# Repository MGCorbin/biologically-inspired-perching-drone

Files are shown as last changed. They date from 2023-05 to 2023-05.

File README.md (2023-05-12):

# Biologically Inspired Perching Drone
This project is inspired by the claws of birds of prey and their unique biological ratcheting mechanism that allows them to tightly and securely grip with their talons without relying entirely on muscular strength.

The files within the project contain both the hardware and software required to build a claw attachment for a drone.

## Directory Structure
* [claw_control/](./biologically-inspired-perching-drone/claw_control)  - folder containing firmware
  * [include/](./biologically-inspired-perching-drone/claw_control/include)
  * [lib/](./biologically-inspired-perching-drone/claw_control/lib)
  * [src/](./biologically-inspired-perching-drone/claw_control/src)
  * [test/](./biologically-inspired-perching-drone/claw_control/test)
  * [platformio.ini](./biologically-inspired-perching-drone/claw_control/platformio.ini)
* [hardware/](./biologically-inspired-perching-drone/hardware)          - folder containing hardware (both electronics & CAD)
* [README.md](./biologically-inspired-perching-drone/README.md)

## Hardware
In this folder you can find STL files that can be downloaded for 3D printing and the original parameterised SolidWorks CAD files and assemblies that can be modified to customise/remix the design to suit different drone and hardware configurations. 
* [Bivalve_7_talon/](./biologically-inspired-perching-drone/hardware/Bivalve_7_talon) - folder containing the Solidworks part files and STL files for a version of the bivalve claw mechanism with additional claws (3-4 config).
* [Bivalve_Claw_Mechanism/](./biologically-inspired-perching-drone/hardware/Bivalve_Claw_Mechanism) - folder containing the SolidWorks part files, STL files, and assembly for the bivalve claw mechanism design.
* [Tendon_Arm/](./biologically-inspired-perching-drone/hardware/Tendon_Arm) - folder contianing the STL files used during the testing and development of the tendon claw design.

## Drone Image
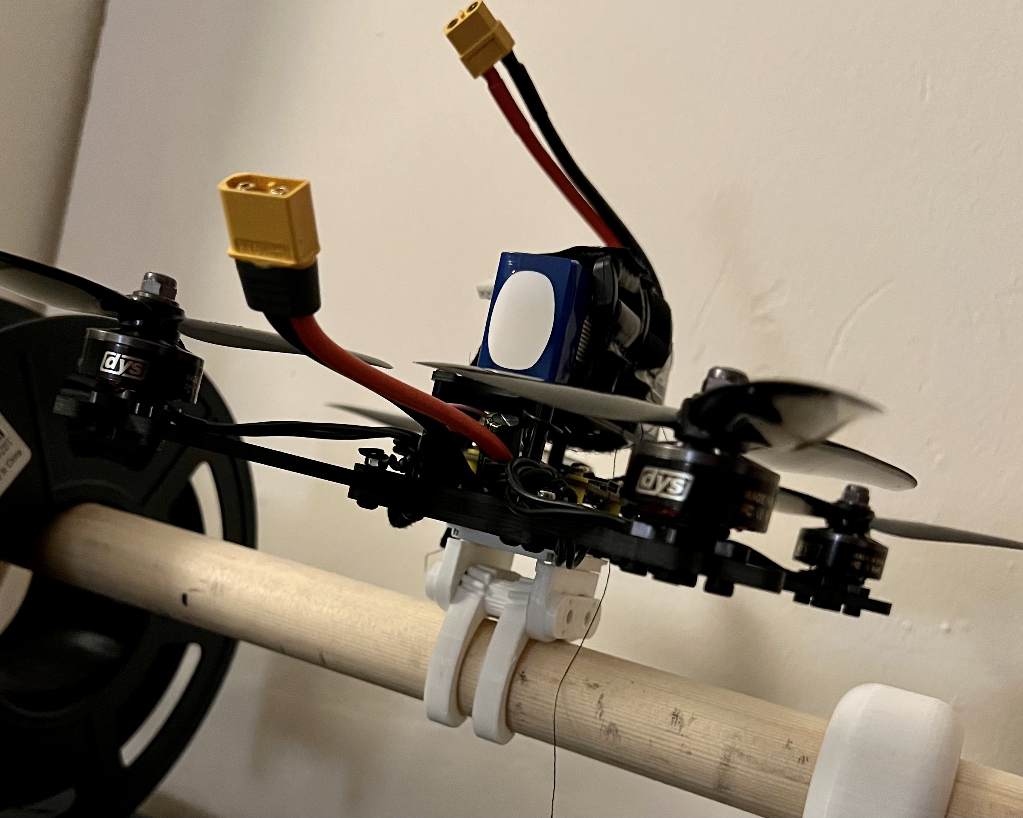
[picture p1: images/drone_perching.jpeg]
drone_perching


## Licenses
Hardware (all files stored under the [hardware](./biologically-inspired-perching-drone/hardware) folder) are under the Creative Commons Attribution-ShareAlike 4.0 International license.

Firmware (all files stored under the [claw_control](./biologically-inspired-perching-drone/claw_control) folder) are under the MIT license.

See each folders LICENSE.txt file for details.

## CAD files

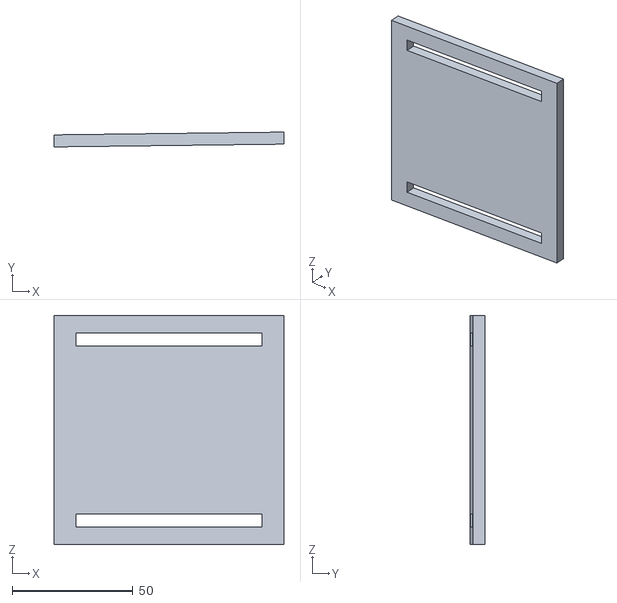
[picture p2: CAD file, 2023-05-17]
hardware/Large_Scale_Claw/Assembly8_main_base_3.stl
95.3 x 6.15 x 95.0

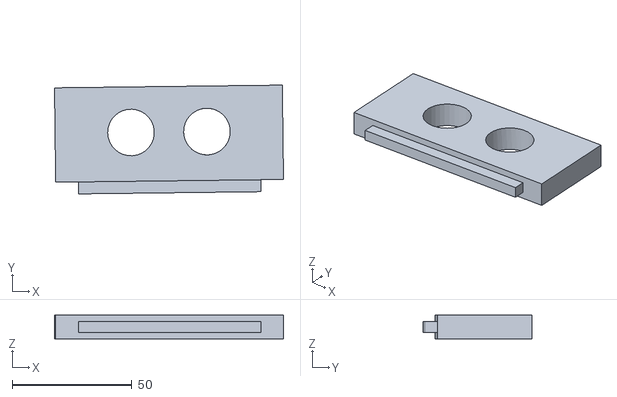
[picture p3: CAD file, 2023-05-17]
hardware/Large_Scale_Claw/Assembly8_secondary_base_5.stl
95.7 x 45.5 x 10.0

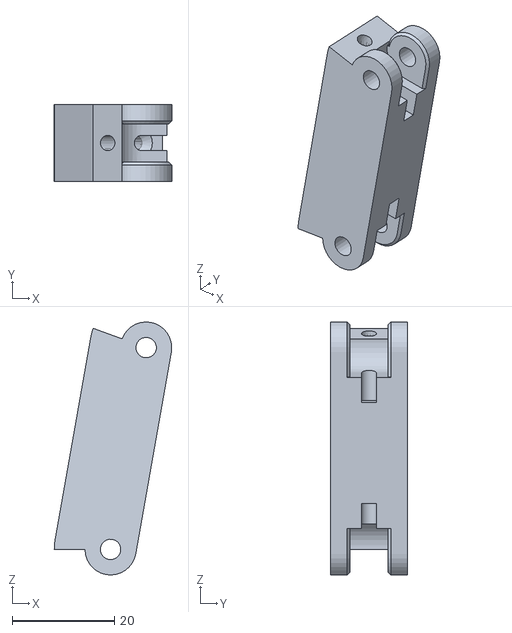
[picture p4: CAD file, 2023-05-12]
hardware/Tendon_Arm/tendon_assembly_tendon_segment_1 (1).stl
22.9 x 15.0 x 49.4

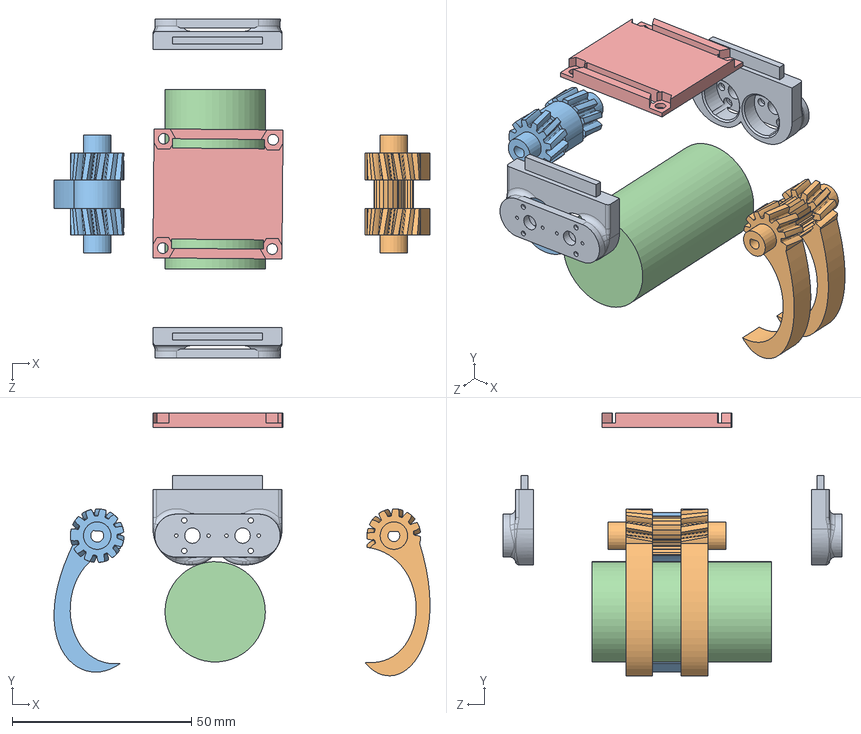
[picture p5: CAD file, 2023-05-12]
hardware/Bivalve_Claw_Mechanism/Assem_itsactuallygonnaworkthistime2.SLDASM
104.9 x 73.3 x 94.5 mm
Mount12VDC x 2
Anterior2.2
PosteriorSingle2.2
TopMount

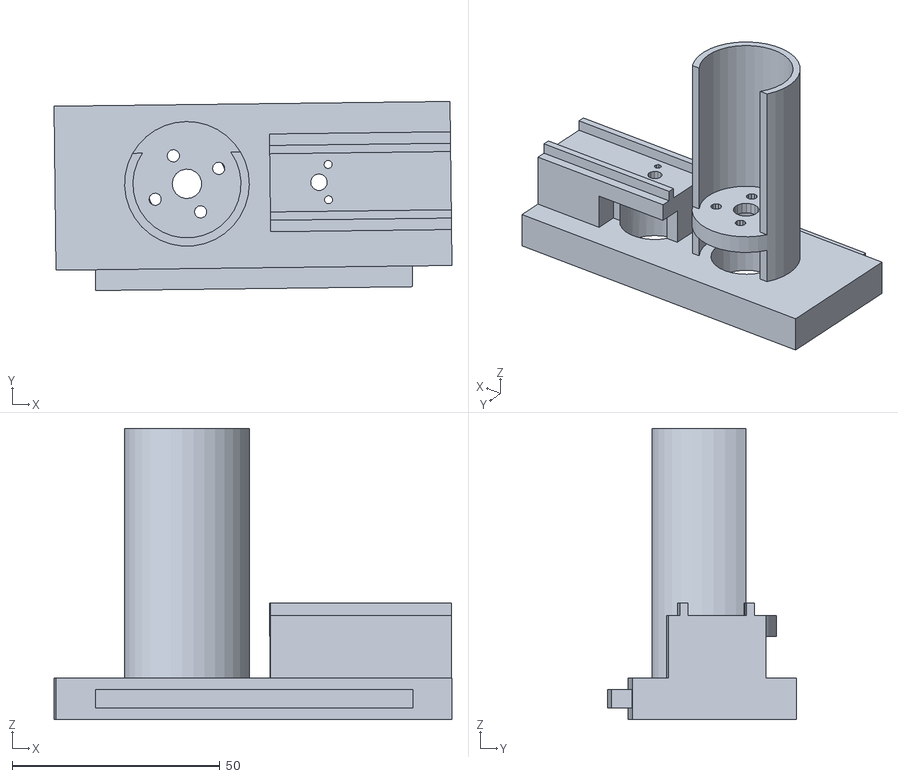
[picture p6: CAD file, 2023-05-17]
hardware/Large_Scale_Claw/Assembly8_secondary_base_4.stl
95.7 x 45.5 x 70.0

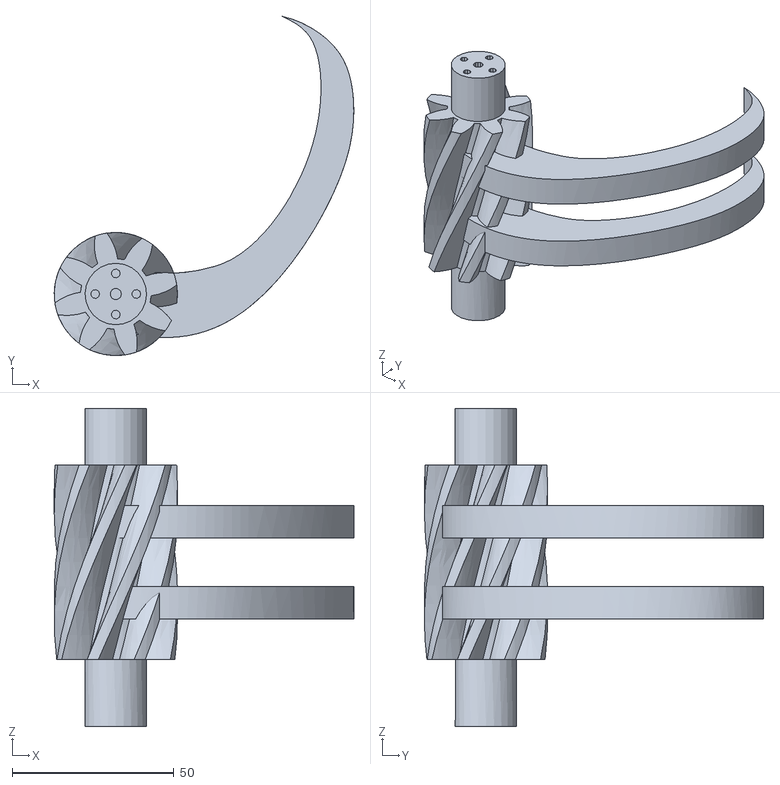
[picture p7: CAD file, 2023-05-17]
hardware/Large_Scale_Claw/Assembly8_arm_2_1.stl
92.6 x 104.8 x 98.3

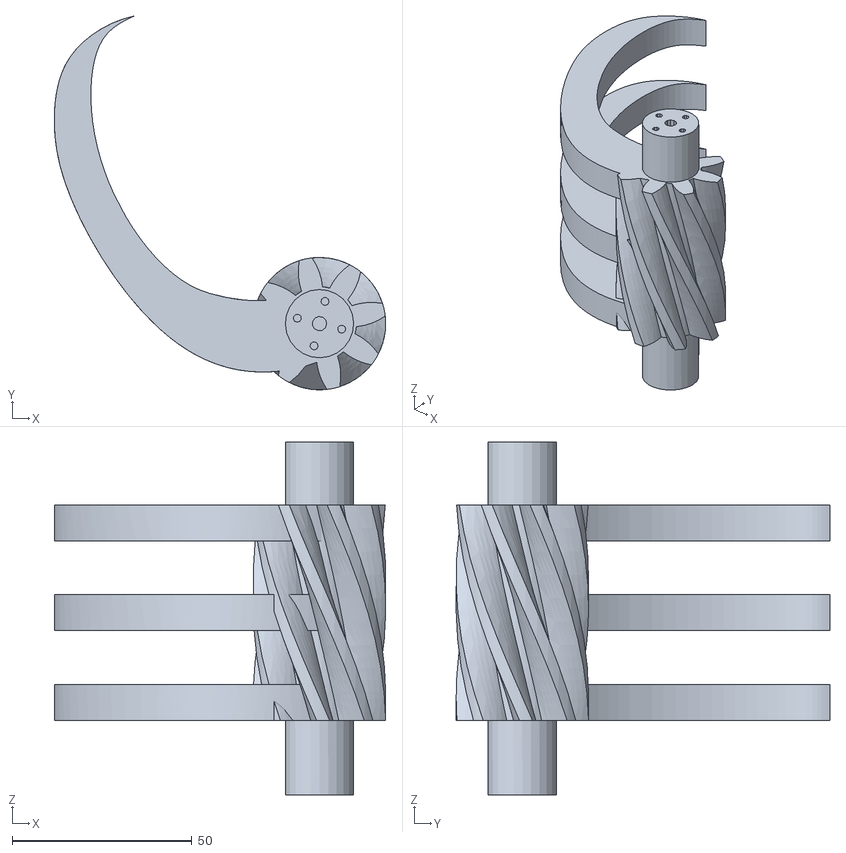
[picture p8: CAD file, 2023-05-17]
hardware/Large_Scale_Claw/Assembly8_arm_3_2.stl
92.2 x 104.0 x 98.3

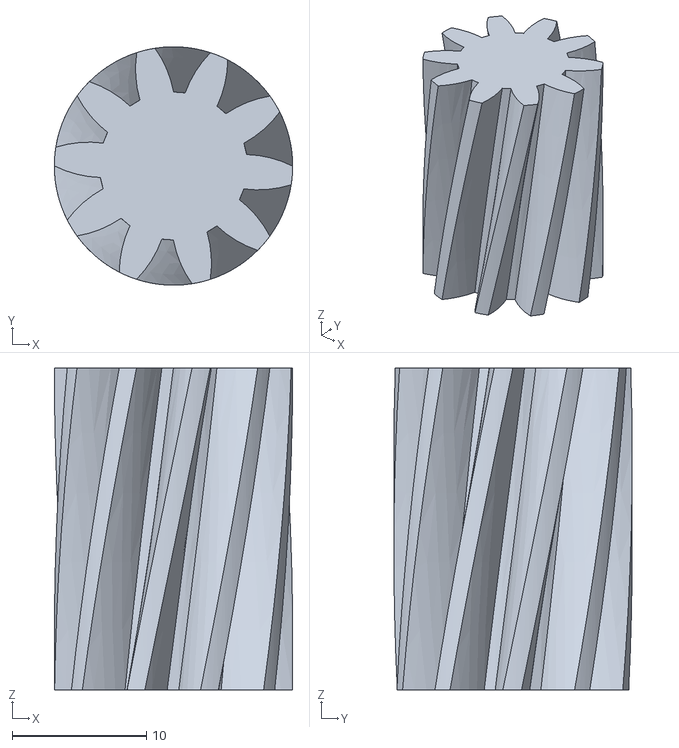
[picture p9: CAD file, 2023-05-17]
hardware/Large_Scale_Claw/Version3/Assembly1_Spur Gear21_5.stl
17.8 x 17.8 x 24.0

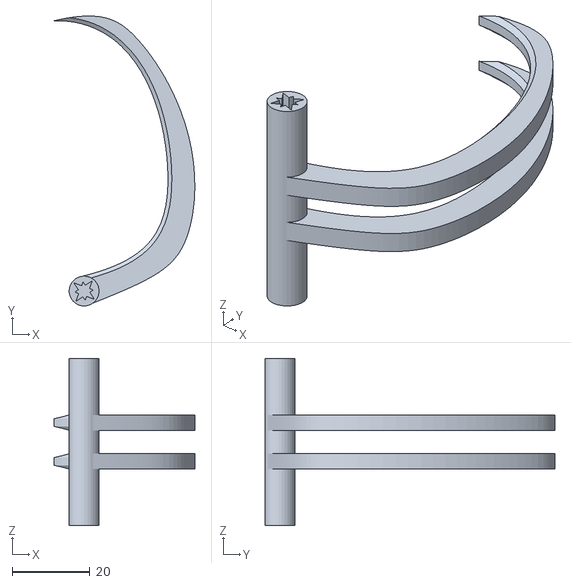
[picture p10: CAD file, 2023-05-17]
hardware/Large_Scale_Claw/Version3/Assembly1_2_arm_3.stl
36.2 x 74.6 x 43.0

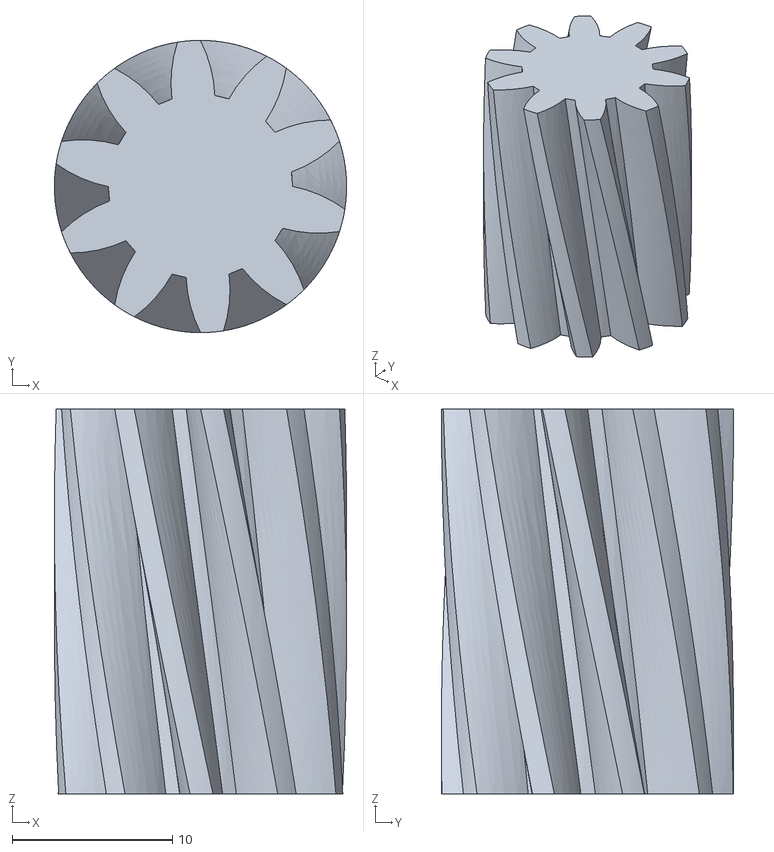
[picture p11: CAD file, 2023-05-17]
hardware/Large_Scale_Claw/Version3/Assembly1_Spur Gear11_4.stl
18.2 x 18.2 x 24.0

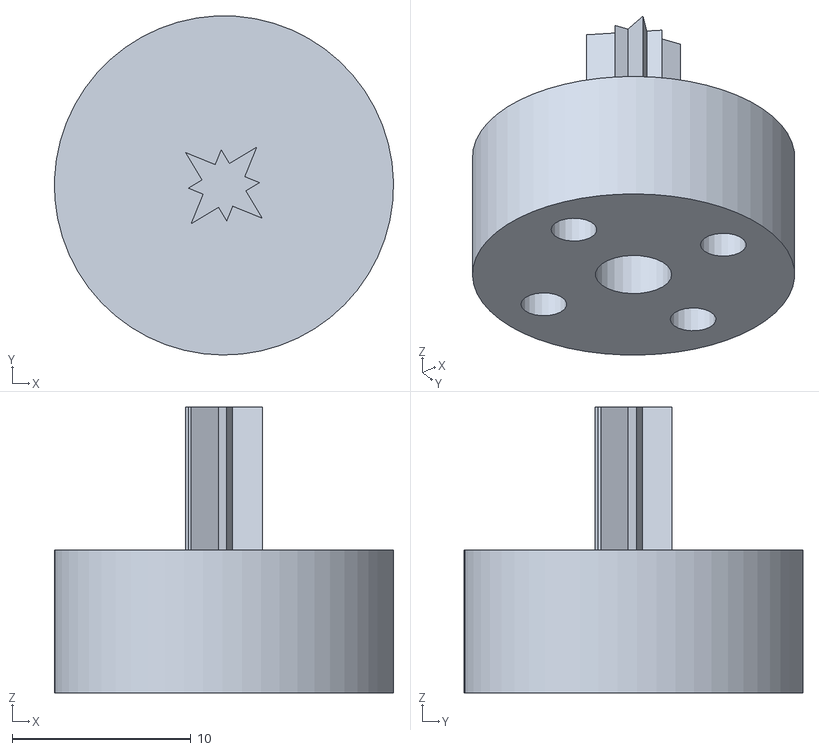
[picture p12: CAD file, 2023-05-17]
hardware/Large_Scale_Claw/Version3/Assembly1_shaft_collar_8.stl
19.0 x 19.0 x 16.0

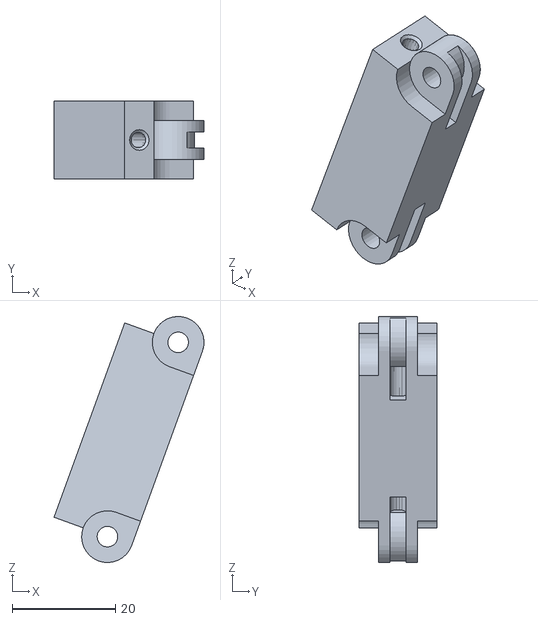
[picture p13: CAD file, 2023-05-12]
hardware/Tendon_Arm/tendon_assembly_tendon_segment2_2 (1).stl
29.0 x 15.0 x 47.6

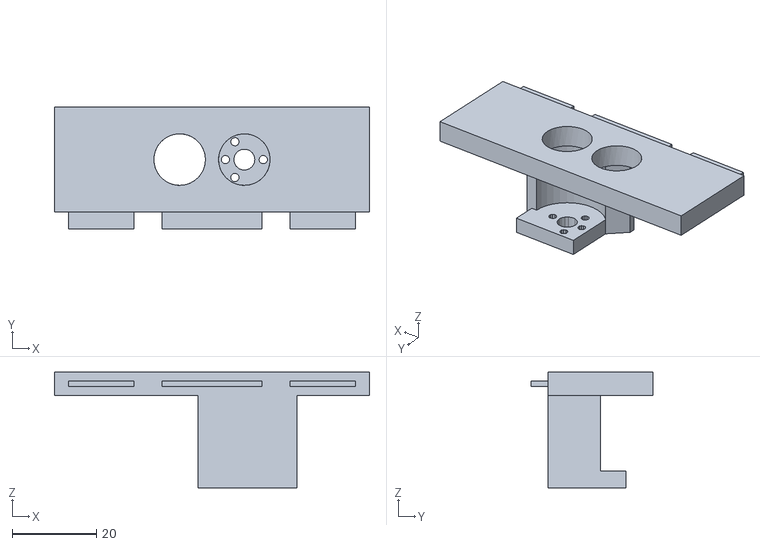
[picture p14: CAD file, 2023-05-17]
hardware/Large_Scale_Claw/Version3/Assembly1_wall_2_7.stl
75.0 x 29.0 x 27.5

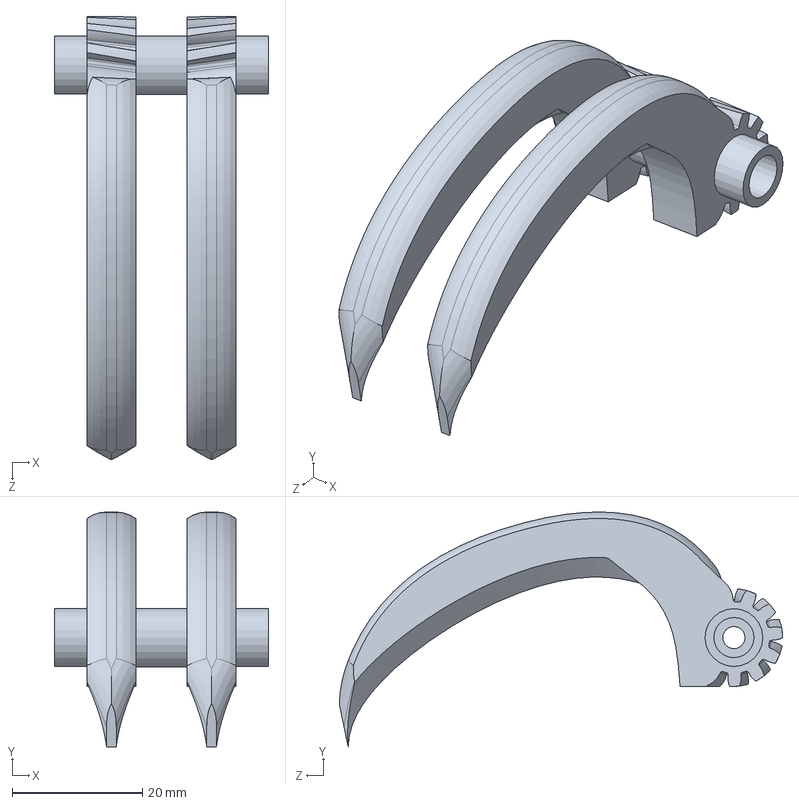
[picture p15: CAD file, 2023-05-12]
hardware/Bivalve_7_talon/Assem2.SLDASM
32.9 x 36.1 x 68.1 mm

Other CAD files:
hardware/Large_Scale_Claw/Version3/Assembly1_wall_2_6.stl
hardware/Large_Scale_Claw/Version3/Assembly1_3_arm_2.stl
hardware/Bivalve_7_talon/Assem1.SLDASM
hardware/Large_Scale_Claw/Version3/Assembly1_base_1.stl
hardware/Bivalve_7_talon/3 talon.STL
hardware/Bivalve_7_talon/3 talon2.STL
hardware/Bivalve_7_talon/4 talon.SLDPRT
hardware/Bivalve_7_talon/4 talon.STL
hardware/Bivalve_7_talon/4 talon2.STL
hardware/Bivalve_7_talon/4 talonscaled.SLDPRT
hardware/Bivalve_7_talon/5m guide new.SLDPRT
hardware/Bivalve_7_talon/Anterior2.2.SLDPRT
hardware/Bivalve_7_talon/Anterior2.2new.SLDPRT
hardware/Bivalve_7_talon/Anterior2.new2.SLDPRT
hardware/Bivalve_7_talon/Anterior2.new3.SLDPRT
hardware/Bivalve_7_talon/Anterior2.new3scaled.SLDPRT
hardware/Bivalve_7_talon/Anterior2.talons.SLDPRT
hardware/Bivalve_7_talon/Anterior2.talonsscaled.SLDPRT
hardware/Bivalve_7_talon/Basenew.SLDPRT
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

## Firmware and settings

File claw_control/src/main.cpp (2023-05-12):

#include <Arduino.h>
#include <Servo.h>
#include "Ultrasonic.h"
#include "motor.h"

// #define TEST_DC_MOTOR       0
#define FC_SWITCH           10
#define ULTRASONIC_PIN      11
#define MOTOR_A             2
#define MOTOR_B             3
#define MOTOR_ADC           A0

Servo servo;
Ultrasonic ultrasonic(ULTRASONIC_PIN);
Motor motor(MOTOR_A, MOTOR_B, MOTOR_ADC);

typedef enum
{
    MANUAL,
    ULTRASONIC
} mode_t;
mode_t mode;

void handle_autoclose(int dist, const int threshold);
int get_dist();

void setup()
{
    // put your setup code here, to run once:
    Serial.begin(115200);
    Serial.println("Startup...");
    servo.attach(9);
    pinMode(FC_SWITCH, INPUT);
    pinMode(MOTOR_A, OUTPUT);
    pinMode(MOTOR_B, OUTPUT);
    pinMode(A0, INPUT);

    delay(100);
    if (digitalRead(7))
    {
        mode = ULTRASONIC;
        Serial.print("ULTRASONIC MODE");
    }
    else
    {
        mode = MANUAL;
        Serial.print("MANUAL MODE");
    }
    delay(1000);
}

void loop()
{
    // long pulsewidth = pulseIn(10, HIGH, 1000);

#ifdef TEST_DC_MOTOR
    static uint16_t hundredMsCount = 0, count = 0;
    static unsigned long oldMillis = 0;
    static uint8_t motor_state = 0;

    if (millis() != oldMillis)
    {
        oldMillis = millis();

        motor.handle();
        motor.setDirection(MotorDirection::FORWARD);
    }


#else

    static uint16_t count = 0;
    static unsigned long oldmilis = 0;
    const uint16_t TIMEOUT = 300;   // number of ms PWM input from FC needs to be high before we say its inactive
    if (millis() != oldmilis)
    {
        oldmilis = millis();
        motor.handle();

        switch (mode)
        {
        case MANUAL:        // manual mode: switch active = close, inactive = open
            if (!digitalRead(FC_SWITCH))
            {
                // Serial.println("CLOSING");
                // servo.write(180);
                motor.setDirection(MotorDirection::FORWARD);
                count = 0;
            }
            else if (count < TIMEOUT)
            {
                count++;
            }
            else
            {
                // Serial.println("Opening - MANUAL");
                // servo.write(90);
                motor.setDirection(MotorDirection::REVERSE);
            }
            break;

        case ULTRASONIC:    // ultrasonic mode: swich active = enable ultrasonic sensor, inactive = open
            if (!digitalRead(FC_SWITCH))
            {
                int distance = get_dist();
                /* ULTRASONIC ENABLED */
                Serial.println("Ultra enabled");
                count = 0;
                Serial.println(count);
                handle_autoclose(distance, 20);
            }
            else if (count < TIMEOUT && digitalRead(FC_SWITCH))
            {
                count++;
            }
            else
            {
                Serial.println("Opening - ULTRA");
                Serial.println(count);
                servo.write(0);
            }
            break;
        }
    }
#endif
}

int get_dist() // call every ms
{
    static int distTimer;
    int RangeInCenti;

    distTimer++;
    if (distTimer >= 100)
    {
        distTimer = 0;
        RangeInCenti = ultrasonic.MeasureInCentimeters();
        Serial.print("Ultrasonic Sensing: ");
        Serial.println(RangeInCenti);
    }

    return RangeInCenti;
}

void handle_autoclose(int dist, const int threshold)
{
    static int autoCloseTimer = 0;
    const int CLOSE_TIME = 100;

    if (dist < threshold)
    {
        autoCloseTimer++;
        if (autoCloseTimer >= CLOSE_TIME)
        {
            /* CLOSE */
            servo.write(180);
        }
    }
    else
    {
        autoCloseTimer = 0;
        servo.write(90); // open if we have closed too early
    }
}

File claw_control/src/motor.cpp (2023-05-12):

#include "motor.h"

/* helper function - doesn't belong to class */
uint16_t adc_to_current(uint16_t adc_count);

Motor::Motor(int pinA, int pinB, int adcPin)
    : m_MotorA(pinA), m_MotorB(pinB), m_ADCpin(adcPin), m_MotorDirection(MotorDirection::STOP), m_Overcurrent(false)
{
    /* empty */
}

void Motor::setDirection(MotorDirection dir)
{
    static MotorDirection oldDirection;

    if(!m_Overcurrent)
    {
        m_MotorDirection = dir;
        return;
    }

    /*
    We have an overcurrent
    Only allow the direction to be set if its opposite to the previous direction
    This stops continuous overccurrents in the same direction
    */

    if(dir == MotorDirection::FORWARD && oldDirection == MotorDirection::REVERSE)
    {
        /* if we WERE reversing, only allow forward */
        m_MotorDirection = dir;
        m_Overcurrent = false;  // clear the overcurrent flag
        Serial.println("Overcurrent cleared. New direction: FORWARD");
    }
    else if(dir == MotorDirection::REVERSE && oldDirection == MotorDirection::FORWARD)
    {
        /* if we WERE going forward, only allow reverse */
        m_MotorDirection = dir;
        m_Overcurrent = false;  // clear the overcurrent flag
        Serial.println("Overcurrent cleared. New direction: REVERSE");
    }

    if(dir == MotorDirection::FORWARD || dir == MotorDirection::REVERSE)
    {
        /* old direction should only be forward or reverse not STOP */
        oldDirection = dir;
    }

}

void Motor::handle()
{
    monitorCurrent();
    switch(m_MotorDirection)
    {
        case MotorDirection::FORWARD:   motorForward(); break;
        case MotorDirection::REVERSE:   motorReverse(); break;
        case MotorDirection::STOP:      motorStop();    break;
    }
}

/* private functions */

void Motor::motorForward()
{
    digitalWrite(m_MotorA, LOW);
    digitalWrite(m_MotorB, LOW);
    _delay_us(10);      // delay to avoid fet fight
    digitalWrite(m_MotorA, HIGH);
}

void Motor::motorReverse()
{
    digitalWrite(m_MotorA, LOW);
    digitalWrite(m_MotorB, LOW);
    _delay_us(10);      // delay to avoid fet fight
    digitalWrite(m_MotorB, HIGH);
}

void Motor::motorStop()
{
    digitalWrite(m_MotorA, LOW);
    digitalWrite(m_MotorB, LOW);
}

void Motor::monitorCurrent()
{
    const uint16_t SAMPLE_SIZE = 10;
    static uint32_t I_buffer = 0;
    static uint16_t sample_count = 0;


    I_buffer += adc_to_current(analogRead(m_ADCpin));
    sample_count ++;

    if(sample_count == SAMPLE_SIZE)
    {
        sample_count = 0;
        m_FilteredCurrent = I_buffer / SAMPLE_SIZE + 1;
        I_buffer = 0;
    }
    detectOvercurrent();

}

void Motor::detectOvercurrent()
{
    static uint16_t overcurrent_count = 0;
    const uint16_t OVERCURRENT_TIME = 200;   // number of ms we need overcurrent for before setting flag
    const uint16_t MOTOR_OVERCURRENT = 500; // value in mA

    if(m_FilteredCurrent > MOTOR_OVERCURRENT)
    {
        overcurrent_count ++;

        if(overcurrent_count > OVERCURRENT_TIME)
        {
            setDirection(MotorDirection::STOP);
            m_Overcurrent = true;
            Serial.println("Motor overcurrent detected");
        }
    }
    else
    {
        overcurrent_count = 0;
    }
}

uint16_t adc_to_current(uint16_t adc_count)
{
    /* returns motor current in mA */
    int temp_v =  (adc_count / 1023.0f) * 5000; // calculate the voltage in mV (5000mV system)
    /* calculate the current
    * divide by 5 as using X5 diff amp,
    * I=V/R - I Sense resistor is 0.5 ohm */
    uint16_t temp_i = (temp_v / 5.0f) / 0.5f;
    return temp_i;
}

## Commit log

2023-05-11 motor control added - needs testing
2023-05-11 motor overcurrent detection fixed. tested in manual mode
    [main.cpp, motor.cpp]
2023-05-12 Initial commit of hardware files
    Consists of the latest iteration of the bivalve claw mechanism SolidWorks part files and assembly and STL files as of this commit.
    [Anterior2.2.SLDPRT, Anterior2.2.STL, Assem_itsactuallygonnaworkthistime2.SLDASM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]
2023-05-12 moved into sub-folder
    [Anterior2.2.SLDPRT, Anterior2.2.STL, Assem_itsactuallygonnaworkthistime2.SLDASM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]
2023-05-12 add 7 talon stl files
    [3 talon.STL, 3 talon2.STL, 4 talon.SLDPRT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]
2023-05-12 Added tendon arm STLs
    [double_base (1).stl, double_base.stl, tendon_C2 (1).stl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]
2023-05-12 Add files via upload
    Added segmented claw design
    [claw design.dwg, claw design_arm1.dwg, claw design_arm2.dwg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]
2023-05-12 moved segmented claw designs to subfolder
    [claw design.dwg, claw design_arm1.dwg, claw design_arm2.dwg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]
2023-05-17 Added new claw geometries
    [2_arm.0011.ipt, 2_arm.ipt, 2_arm_with_gear.ipt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]
2023-05-19 Added new hardware
    [2_arm.0011.ipt, 2_arm.0013.ipt, 2_arm.0015.ipt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]
